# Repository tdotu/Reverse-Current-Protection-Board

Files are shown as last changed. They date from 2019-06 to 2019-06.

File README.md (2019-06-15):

# Reverse-Current-Protection-Board
A Reverse Current Protection Board that allows the safe paralell usage of two Battery packs with different capacities.
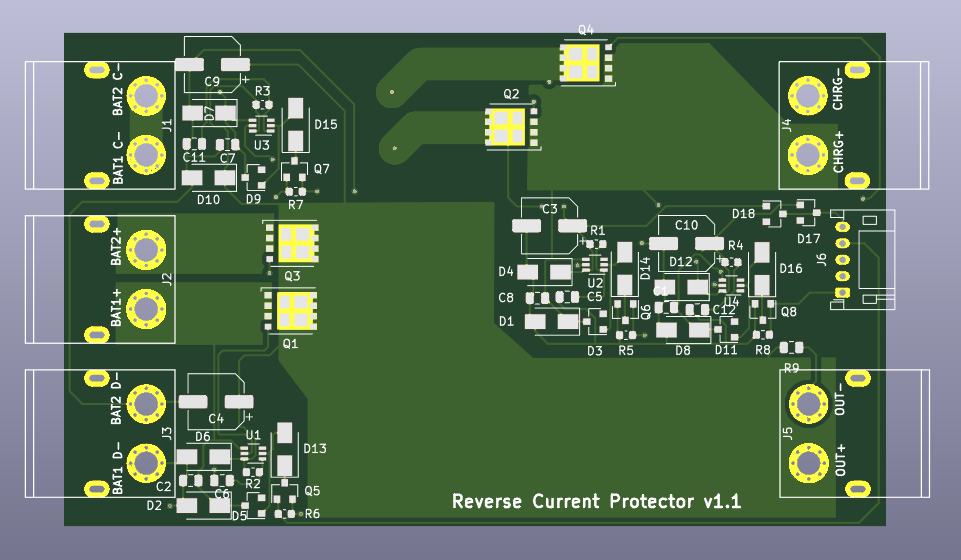
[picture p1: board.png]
Screenshot of the Board


## What it does

I developed this board because I wanted to use two 10S5P battery packs with different cells in paralell. Each of the packs has it's own BMS with seperate charge and discharge negative pole. This board takes care that the two packs do not charge and discharge each ohter. It also allows the enableing and disableing of the charing and discharging of each pack.

## Electrical limits
This board is designed for a maximal load of 55A on the discharge output when it is
fabricated with 70µm (2oz) of copper. It can be used up until a 14s (48V) battery packs.

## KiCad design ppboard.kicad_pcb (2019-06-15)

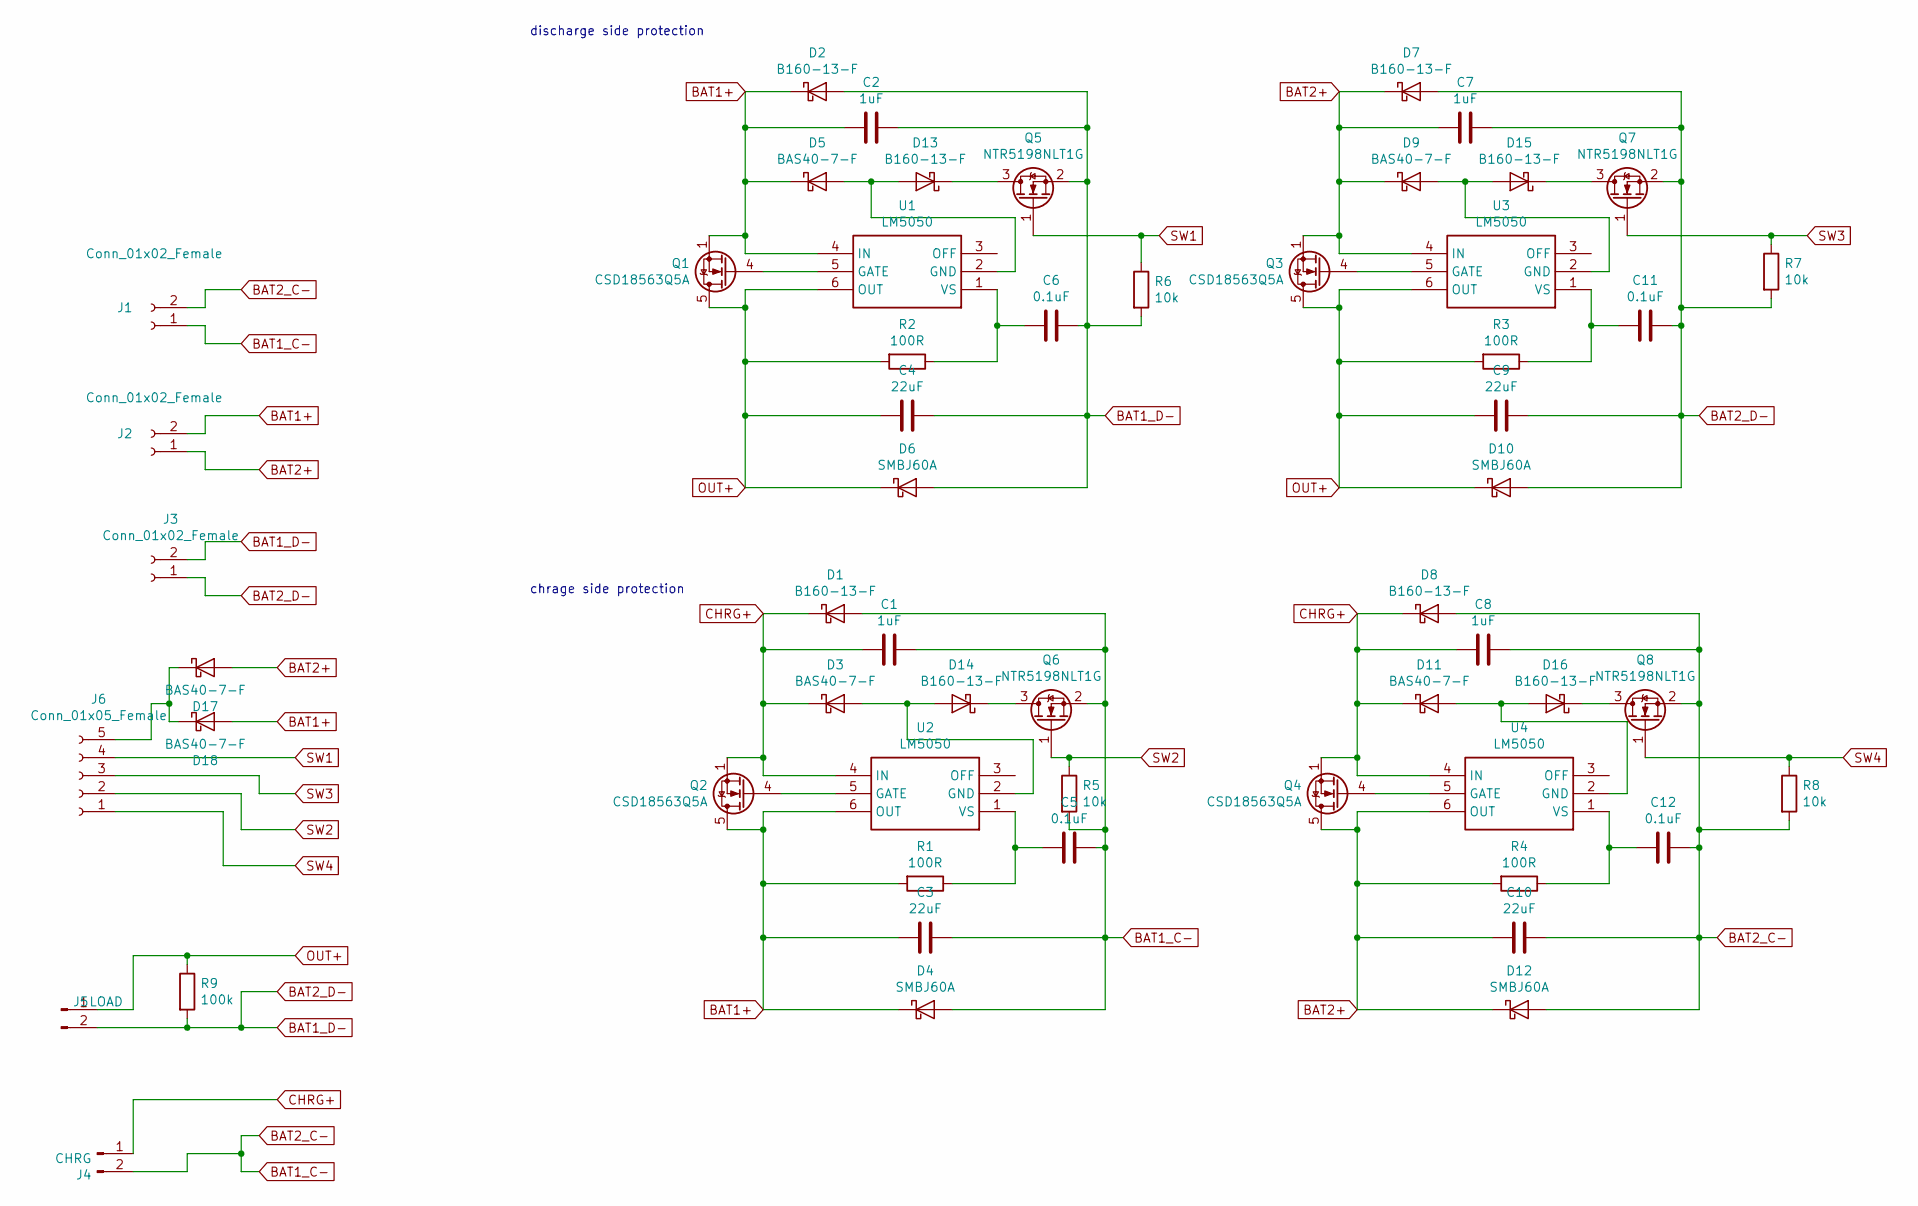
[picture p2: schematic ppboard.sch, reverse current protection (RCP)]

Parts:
C1, C7, C8: 1uF; C_0805_2012Metric; voltage 75v
C2: 1uF; C_0805_2012Metric; voltage 75V
C3, C4, C9, C10: 22uF; CP_Elec_6.3x5.2
C5, C11: 0.1uF; C_0805_2012Metric; voltage 100V
C6, C12: 0.1uF; C_0805_2012Metric; Voltage 100V
D1, D7, D8, D13, D14, D15, D16: B160-13-F; D_SMA
D2: B160-13-F; D_SMA; voltage 60V
D3, D5, D9, D11, D17, D18: BAS40-7-F; D_SOT-23_ANK
D4, D6, D10, D12: SMBJ60A; D_SMA
J1, J2, J3: Conn_01x02_Female; XT60PW
J4: CHRG; XT60PW
J5: LOAD; XT60PW
J6: Conn_01x05_Female; JST_PH_S5B-PH-K_1x05_P2.00mm_Horizontal
Q1, Q2, Q3, Q4: CSD18563Q5A; TDSON-8-1
Q5, Q6, Q7, Q8: NTR5198NLT1G; SOT-23
R1, R2, R3, R4: 100R; R_0603_1608Metric
R5, R6, R7, R8: 10k; R_0603_1608Metric
R9: 100k; R_0805_2012Metric
U1, U2, U3, U4: LM5050; Texas_R-PDSO-G6

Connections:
BAT1+: C2.2, C3.1, D2.1 (K), D4.1 (K), D5.1 (K), D18.2 (A), J2.2, Q1.1 (S), Q1.2 (S), Q1.3 (S), Q2.5 (D), R1.2, U1.4 (IN), U2.6 (OUT)
BAT1_C-: C1.1, C3.2, C5.2, C8.1, C10.2, C12.2, D1.2 (A), D4.2 (A), D8.2 (A), D12.2 (A), J1.1, J1.2, J4.2, Q6.2 (S), Q8.2 (S), R5.2, R8.2
BAT1_D-: C2.1, C4.2, C6.2, C7.1, C9.2, C11.2, D2.2 (A), D6.2 (A), D7.2 (A), D10.2 (A), J3.1, J3.2, J5.2, Q5.2 (S), Q7.2 (S), R6.2, R7.2, R9.2
BAT2+: C7.2, C10.1, D7.1 (K), D9.1 (K), D12.1 (K), D17.2 (A), J2.1, Q3.1 (S), Q3.2 (S), Q3.3 (S), Q4.5 (D), R4.2, U3.4 (IN), U4.6 (OUT)
CHRG+: C1.2, C8.2, D1.1 (K), D3.1 (K), D8.1 (K), D11.1 (K), J4.1, Q2.1 (S), Q2.2 (S), Q2.3 (S), Q4.1 (S), Q4.2 (S), Q4.3 (S), U2.4 (IN), U4.4 (IN)
unnamed: C5.1, R1.1, U2.1 (VS)
unnamed: C6.1, R2.1, U1.1 (VS)
unnamed: C11.1, R3.1, U3.1 (VS)
unnamed: C12.1, R4.1, U4.1 (VS)
unnamed: D11.2 (A), D16.2 (A), U4.2 (GND)
unnamed: D13.1 (K), Q5.3 (D)
unnamed: D5.2 (A), D13.2 (A), U1.2 (GND)
unnamed: D14.1 (K), Q6.3 (D)
unnamed: D3.2 (A), D14.2 (A), U2.2 (GND)
unnamed: D15.1 (K), Q7.3 (D)
unnamed: D9.2 (A), D15.2 (A), U3.2 (GND)
unnamed: D16.1 (K), Q8.3 (D)
unnamed: D17.1 (K), D18.1 (K), J6.5
unnamed: Q1.4 (G), U1.5 (GATE)
unnamed: Q2.4 (G), U2.5 (GATE)
unnamed: Q3.4 (G), U3.5 (GATE)
unnamed: Q4.4 (G), U4.5 (GATE)
OUT+: C4.1, C9.1, D6.1 (K), D10.1 (K), J5.1, Q1.5 (D), Q3.5 (D), R2.2, R3.2, R9.1, U1.6 (OUT), U3.6 (OUT)
SW1: J6.4, Q5.1 (G), R6.1
SW2: J6.2, Q6.1 (G), R5.1
SW3: J6.3, Q7.1 (G), R7.1
SW4: J6.1, Q8.1 (G), R8.1

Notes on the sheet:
chrage side protection
discharge side protection

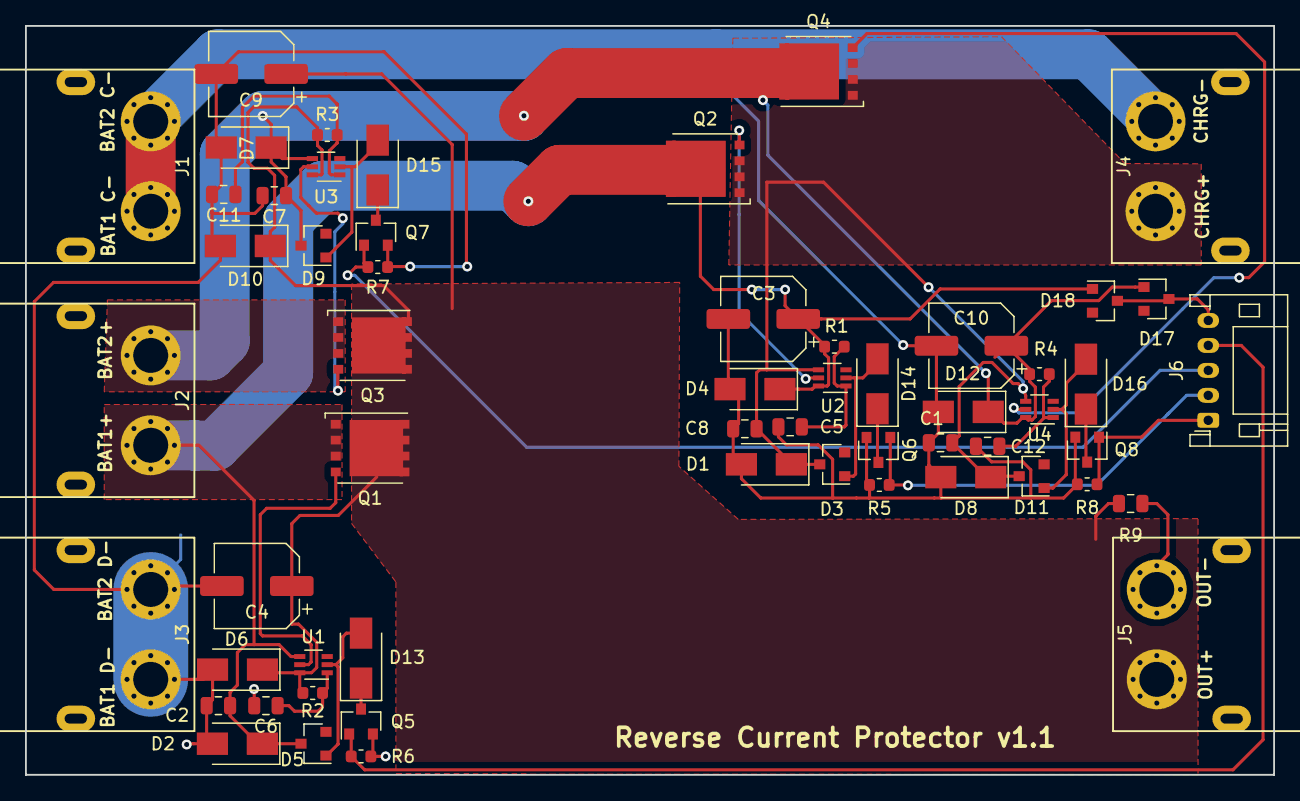
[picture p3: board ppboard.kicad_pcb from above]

Board: 2 copper layers, 100.0 x 60.0 mm, 57 parts (0 on the bottom side), 27 nets.
